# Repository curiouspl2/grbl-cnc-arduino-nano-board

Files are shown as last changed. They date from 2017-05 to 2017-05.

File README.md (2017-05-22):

A PCB layout and schematic.

this is my fork with following features :

 * simple single sided board suitable for isolation routing
 * cheaper arduino mini instead of nano (no usb), can be used with my simplified single-sided arduino clone
 * additional A axis instead of spindle enable
 * ISP header (grbl cannot be programmed with bootloader anyway as it's too big)

TODO:
 * messy schematic and board, needs fixing
 * still using arduino nano header (unused pins just not connected) 
 * board is not really optimised
 * additional headers for tx/rx, fdti, additional arduino mini to support SD card, lcd and encoder

Made with Eagle PCB 8

##Requirements
* an arduino mini w atmega328 loaded with grbl http://github.com/grbl/grbl
* ISP programmer
* at least 1 Pololu A4988 Stepper motor driver
* power supply and motor ofcourse.

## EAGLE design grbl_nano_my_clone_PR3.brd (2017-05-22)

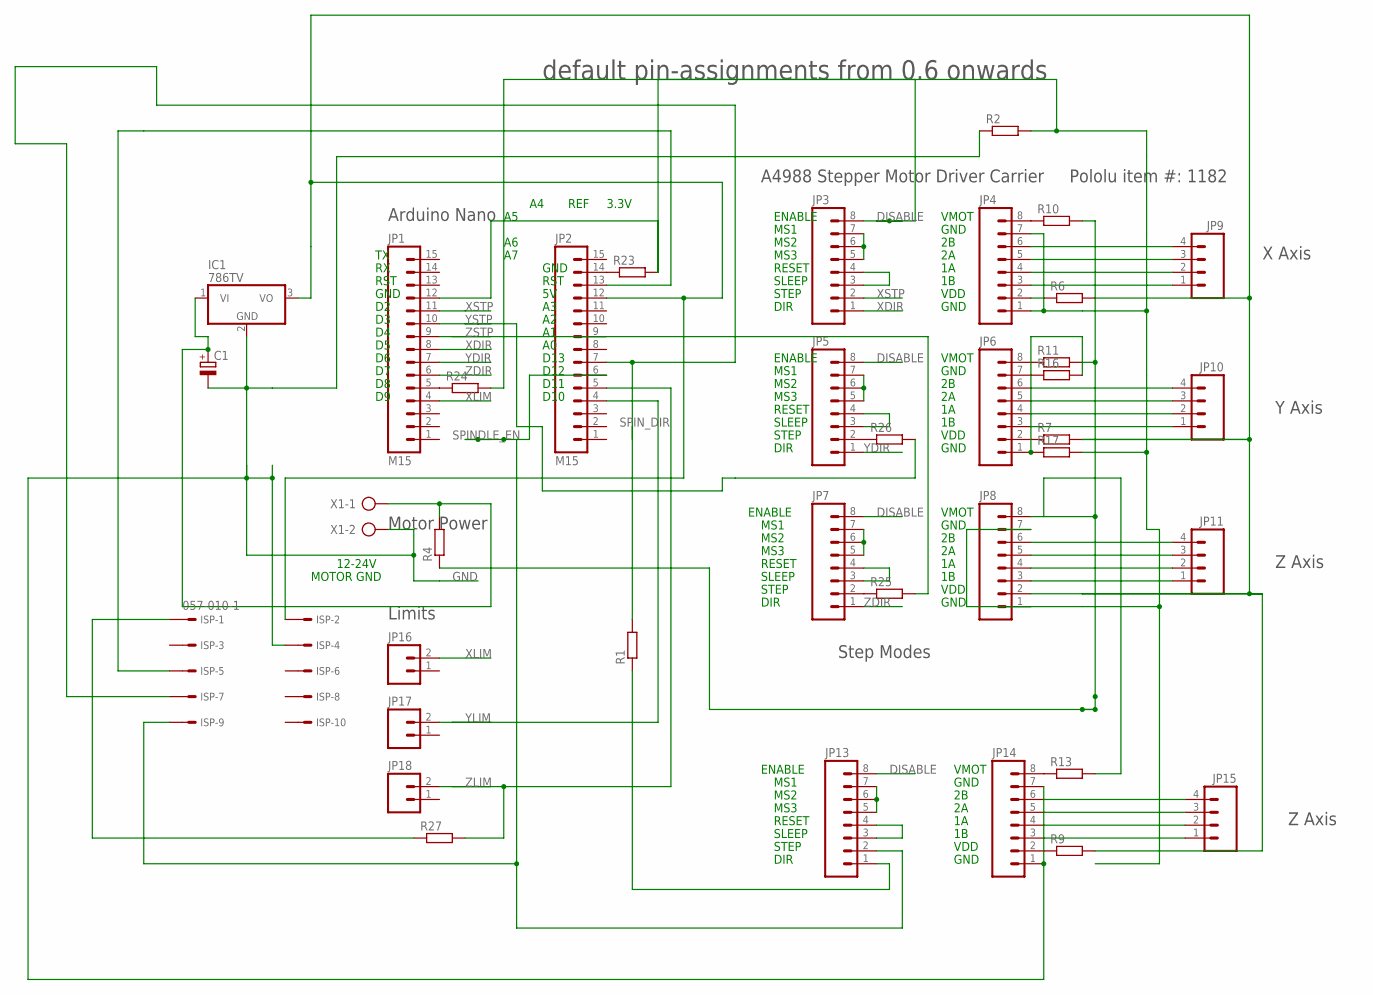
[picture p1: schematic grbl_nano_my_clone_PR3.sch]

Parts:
C1: CPOL-EUE3.5-8; E3,5-8
IC1: 786TV; TO220V
ISP: 057-010-1
JP1, JP2: M15; 1X15
JP3, JP4, JP5, JP6, JP7, JP8, JP13, JP14: M08LONGPADS; 1X08_LONGPADS
JP9, JP10, JP11, JP15: M04LONGPADS; 1X04_LONGPADS
JP16, JP17, JP18: M02LOCK_LONGPADS; 1X02_LOCK_LONGPADS
R1, R2, R6, R7, R9, R13, R23, R24, R25, R26, R27: R-EU_0207/15; 0207/15
R4, R16, R17: R-EU_0207/12; 0207/12
R10, R11: R-EU_0207/7; 0207/7
X1: AK300/2

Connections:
5V: IC1.3 (VO), ISP.2, JP2.12, JP8.2, R6.2, R7.2, R9.2
DISABLE: JP3.8, JP5.8, JP7.8, JP13.8, R24.2
GND: C1.-, IC1.2 (GND), ISP.4, JP14.1, JP14.7, R2.1, X1.2
GNDINT: JP1.12, JP4.1, JP4.7, JP8.1, JP8.7, R2.2, R17.2, R23.2
unnamed: JP5.3, JP5.4
unnamed: JP4.6, JP9.4
unnamed: JP4.5, JP9.3
unnamed: JP4.4, JP9.2
unnamed: JP4.3, JP9.1
unnamed: JP8.6, JP11.4
unnamed: JP8.5, JP11.3
unnamed: JP8.4, JP11.2
unnamed: JP8.3, JP11.1
unnamed: JP6.6, JP10.4
unnamed: JP6.5, JP10.3
unnamed: JP6.4, JP10.2
unnamed: JP6.3, JP10.1
unnamed: JP7.3, JP7.4
unnamed: JP3.3, JP3.4
unnamed: JP14.6, JP15.4
unnamed: JP14.5, JP15.3
unnamed: JP14.4, JP15.2
unnamed: JP14.3, JP15.1
unnamed: JP13.3, JP13.4
unnamed: JP13.1, R1.1
unnamed: ISP.5, JP2.13
unnamed: JP4.2, R6.1
unnamed: C1.+, IC1.1 (VI), R4.2, X1.1
unnamed: JP4.8, R10.1
unnamed: JP3.5, JP3.6, JP3.7
unnamed: JP5.2, R26.1
unnamed: JP14.2, R9.1
unnamed: JP6.8, R11.1
unnamed: JP14.8, R13.1
unnamed: JP6.7, R16.1
unnamed: JP6.1, R16.2, R17.1
unnamed: JP2.14, R23.1
unnamed: JP1.5, R24.1
unnamed: JP7.2, R25.1
unnamed: JP6.2, R7.1
unnamed: JP5.5, JP5.6, JP5.7
unnamed: ISP.1, R27.1
unnamed: JP7.5, JP7.6, JP7.7
unnamed: JP13.5, JP13.6, JP13.7
SPINDLE_EN: ISP.9, JP2.6, JP13.2
SPIN_DIR: ISP.7, JP2.7, R1.2
VMOT: JP8.8, R4.1, R10.2, R11.2, R13.2
XDIR: JP1.8, JP3.1
XLIM: JP1.4, JP16.2
XSTP: JP1.11, JP3.2
YDIR: JP1.7, JP5.1
YLIM: JP2.4, JP17.2
YSTP: JP1.10, R26.2
ZDIR: JP1.6, JP7.1
ZLIM: JP2.5, JP18.2, R27.2
ZSTP: JP1.9, R25.2

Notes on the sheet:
D10
GND
D11
D12
DIR
STEP
SLEEP
MS3
MS2
MS1
ENABLE
RESET
VDD
VMOT
default pin-assignments from 0.6 onwards
Step Modes
Arduino Nano
A4988 Stepper Motor Driver Carrier
Pololu item #: 1182
Motor Power
RST
REF
3.3V
D13
12-24V
MOTOR GND
Limits
X Axis
Y Axis
Z Axis

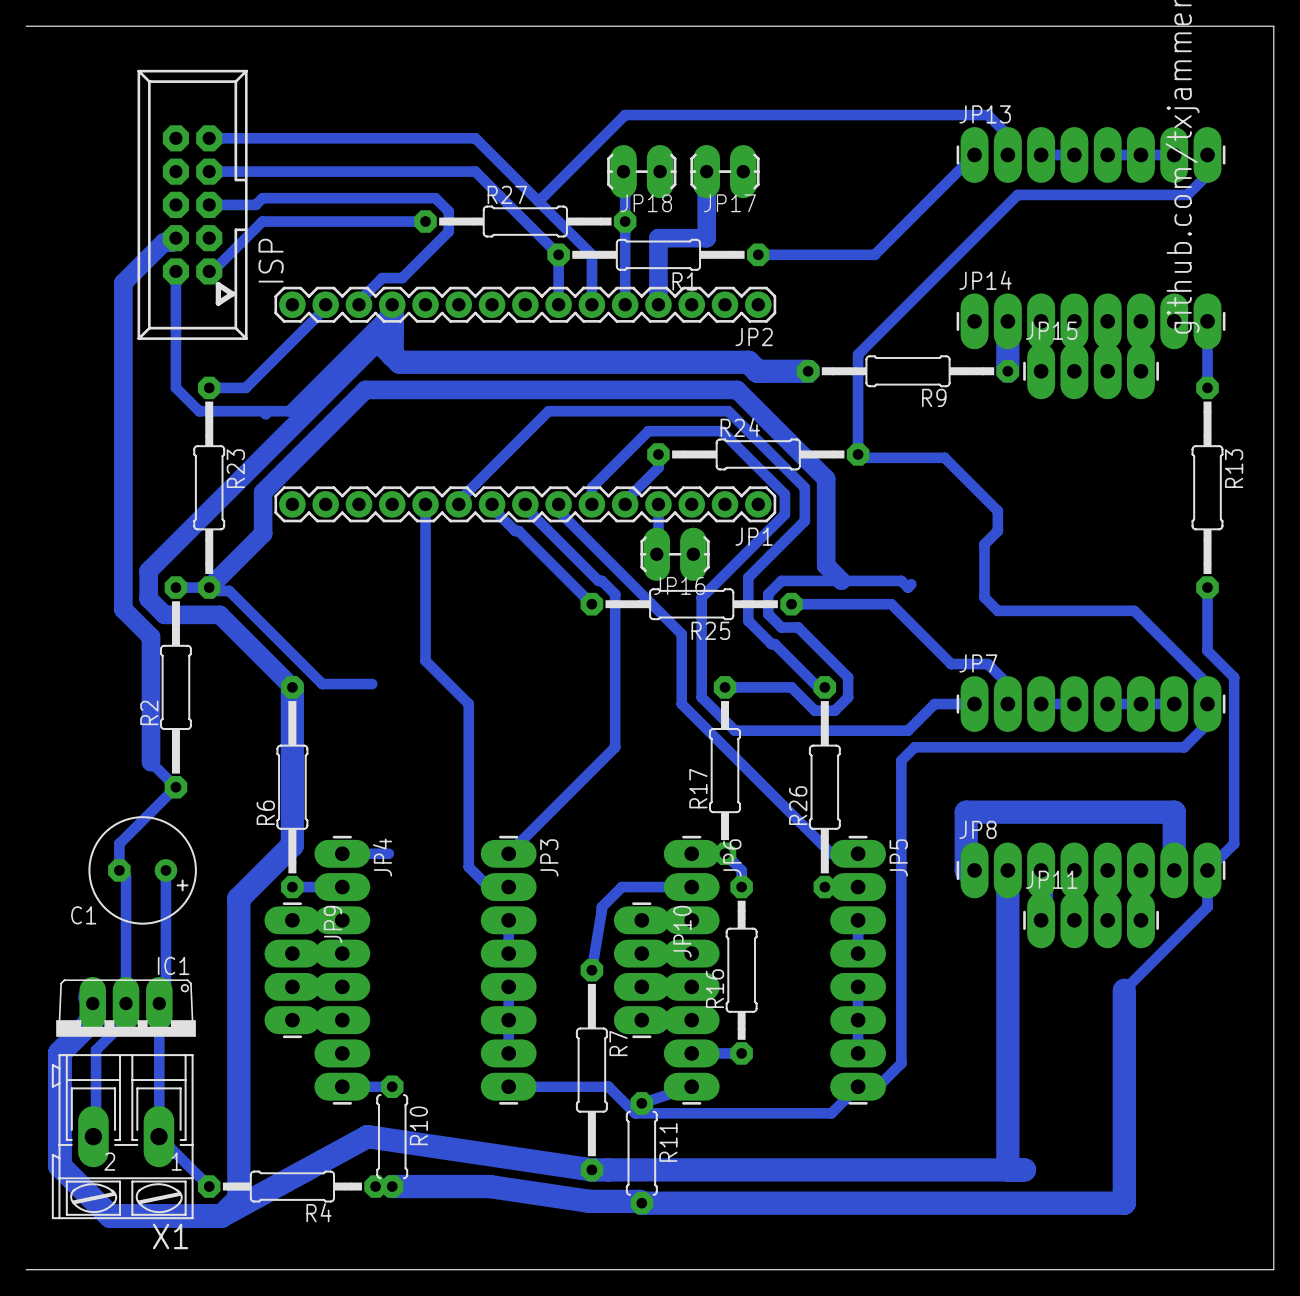
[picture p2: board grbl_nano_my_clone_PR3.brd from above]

Board: 2 copper layers, 95.2 x 94.9 mm, 37 parts (0 on the bottom side), 56 nets.
